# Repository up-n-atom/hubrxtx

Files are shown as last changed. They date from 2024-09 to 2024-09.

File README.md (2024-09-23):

# hubrxtx
Home Hub 4000 / Giga Hub serial USB jig



hubrxtx render

Demo

# Bill of Materials

## Required

| Ref. | Value | [LCSC](https://www.lcsc.com/) | [AliExpress](https://www.aliexpress.com) | Qty. |
| -- | -- | -- | -- | --:  |
| C3 | 0.1 uF | [C2930551](https://www.lcsc.com/product-detail/Multilayer-Ceramic-Capacitors-MLCC-SMD-SMT_YAGEO-CC0603KRX5R8BB104_C2930551.html) |  | 1 |
| U1 | CH340K | [C18208922](https://www.lcsc.com/product-detail/USB-Converters_WCH-Jiangsu-Qin-Heng-CH340K_C18208922.html) | <https://s.click.aliexpress.com/e/_mKKYYbw> | 1 |
| J1 | USB B Micro  | [C145795](https://www.lcsc.com/product-detail/USB-Connectors_Korean-Hroparts-Elec-U-D-M5DD-W-1_C145795.html) | <https://s.click.aliexpress.com/e/_mMzctcY> | 1 |
| TP1, TP2, TP3, TP4 | P100-H2 |  | <https://s.click.aliexpress.com/e/_mO8N2oG> | 4 |
| Plastic Rivet | R4060 |  | <https://a.aliexpress.com/_m0u7X0g> | 2 |

## Optional - LEDs

| Ref. | Value | [LCSC](https://www.lcsc.com/) | Qty. |
| -- | -- | -- | --:  |
| R1 | 220 Ohm | [C304718](https://www.lcsc.com/product-detail/Chip-Resistor-Surface-Mount_FH-Guangdong-Fenghua-Advanced-Tech-RS-03K2200FT_C304718.html) | 1 |
| R2, R3 | 22 Ohm | [C2907129](https://www.lcsc.com/product-detail/Chip-Resistor-Surface-Mount_FOJAN-FRC0603J220-TS_C2907129.html) | 2 |
| D1 | Red | [C965799](https://www.lcsc.com/product-detail/span-style-background-color-ff0-LED-span-Indication-Discrete_XINGLIGHT-XL-1608SURC-06_C965799.html) | 1 |
| D2 | White | [C965808](https://www.lcsc.com/product-detail/LED-Indication-Discrete_XINGLIGHT-XL-1608UWC-04_C965808.html) | 1 |
| D3 | Blue | [C965807](https://www.lcsc.com/product-detail/LED-Indication-Discrete_XINGLIGHT-XL-1608UBC-04_C965807.html) | 1 |

## Optional - USB power

| Ref. | Value | [LCSC](https://www.lcsc.com/) | Qty. |
| -- | -- | -- | --:  |
| C1, C2 | 1.0 uF | [C7503503](https://www.lcsc.com/product-detail/Multilayer-Ceramic-Capacitors-MLCC-SMD-SMT_HRE-CGA0603X7R105K250JT_C7503503.html) | 2 |
| F1 | 200 mA | [C210356](https://www.lcsc.com/product-detail/Resettable-Fuses_BOURNS-MF-FSMF020X-2_C210356.html) | 1 |
| U2 | XC6206P332MR | [C5148692](https://www.lcsc.com/product-detail/Voltage-Regulators-Linear-Low-Drop-Out-LDO-Regulators_HXY-MOSFET-XC6206P332MR_C5148692.html) | 1 |

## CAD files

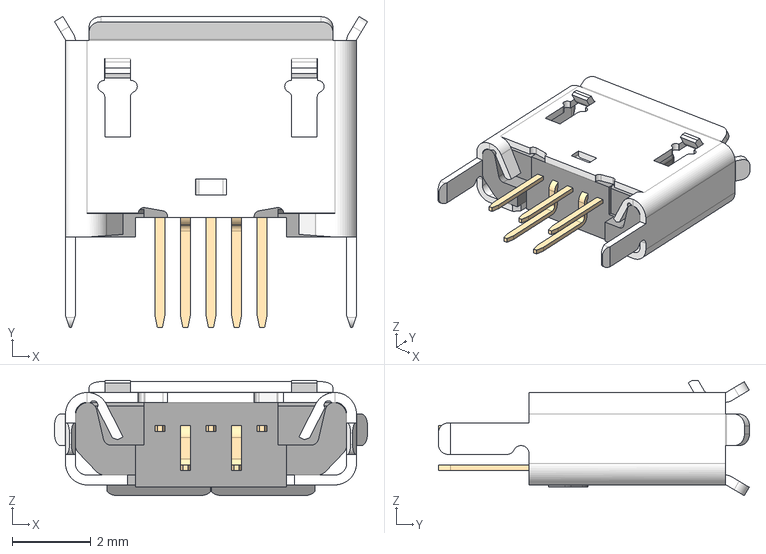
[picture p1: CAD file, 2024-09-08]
3dshapes/USB3106-30-0230-A.step
7.96 x 7.91 x 2.94 mm

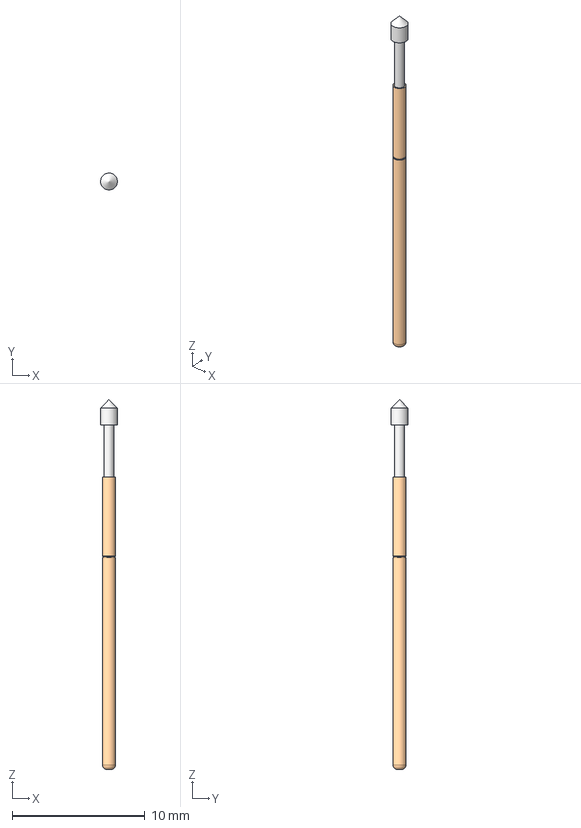
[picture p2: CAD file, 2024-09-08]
3dshapes/POGO-PIN.step
1.27 x 1.27 x 27.8 mm

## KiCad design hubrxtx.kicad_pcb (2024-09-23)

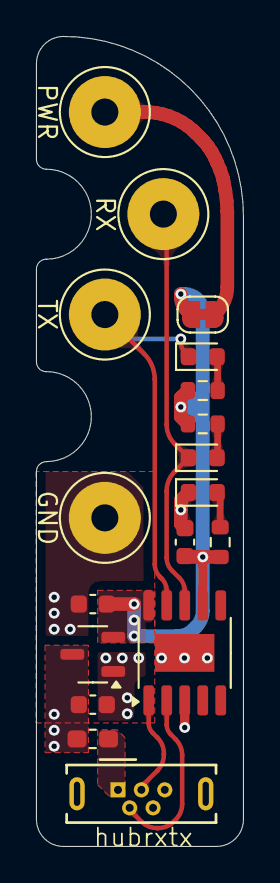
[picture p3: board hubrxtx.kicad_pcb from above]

Board: 2 copper layers, 11.5 x 45.0 mm, 18 parts (0 on the bottom side), 12 nets.

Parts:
C1, C2: 1uF; C_0603_1608Metric
C3: 0.1uF; C_0603_1608Metric
D1: RED; LED_0603_1608Metric
D2: WHITE; LED_0603_1608Metric
D3: BLUE; LED_0603_1608Metric
F1: 200mA; Fuse_0603_1608Metric_Pad1.05x0.95mm_HandSolder
J1: USB_B_Micro; USB_Micro-B_Wuerth_614105150721_Vertical
JP1: power; SolderJumper-2_P1.3mm_Bridged_RoundedPad1.0x1.5mm
R1: 220Ω; R_0603_1608Metric
R2, R3: 22Ω; R_0603_1608Metric
TP1: PWR; TestPoint_Pad_D4.0mm
TP2: RX; TestPoint_Pad_D4.0mm
TP3: TX; TestPoint_Pad_D4.0mm
TP4: GND; TestPoint_Pad_D4.0mm
U1: CH340K; SSOP-10-1EP_3.9x4.9mm_P1mm_EP2.1x3.3mm
U2: XC6206PxxxMR; SOT-23-3

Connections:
GND: C1.2, C2.2, C3.1, D1.1 (K), J1.5 (GND), J1.6 (Shield), TP4.1, U1.3 (GND), U1.11 (GND), U2.1 (GND)
unnamed: D1.2 (A), R1.1
unnamed: D2.2 (A), R2.1
unnamed: D3.2 (A), R3.1
unnamed: J1.3 (D+), U1.1 (UD+)
unnamed: J1.2 (D-), U1.2 (UD-)
unnamed: F1.1, J1.1 (VBUS)
unnamed: JP1.2 (B), TP1.1
unnamed: D3.1 (K), TP3.1, U1.9 (RXD)
unnamed: D2.1 (K), TP2.1, U1.8 (TXD)
VBUS: C1.1, F1.2, U2.3 (VI)
VCC: C2.1, C3.2, JP1.1 (A), R1.2, R2.2, R3.2, U1.7 (VCC), U1.10 (V3), U2.2 (VO)

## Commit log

2024-09-08 Add KiCAD project files
    [POGO-PIN.step, USB3106-30-0230-A.step, hubrxtx.kicad_pcb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]
2024-09-23 Update KiCad project
    * Cleanup schematic
    * Add net classes
    [hubrxtx.kicad_pcb, hubrxtx.kicad_sch]
2024-09-23 README: Add BOM
